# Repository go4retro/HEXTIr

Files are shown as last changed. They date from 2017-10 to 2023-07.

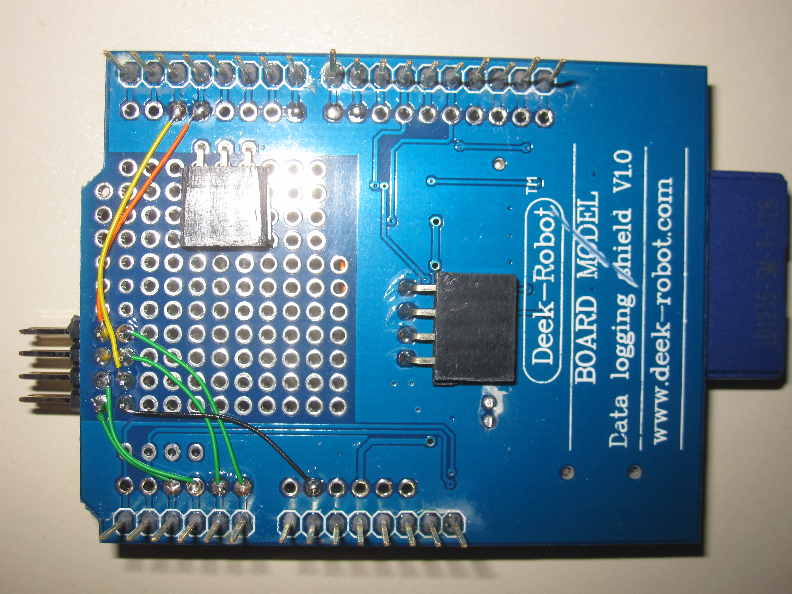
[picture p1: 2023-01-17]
doc/arduino/Arduino SD Shield Bottom.jpg

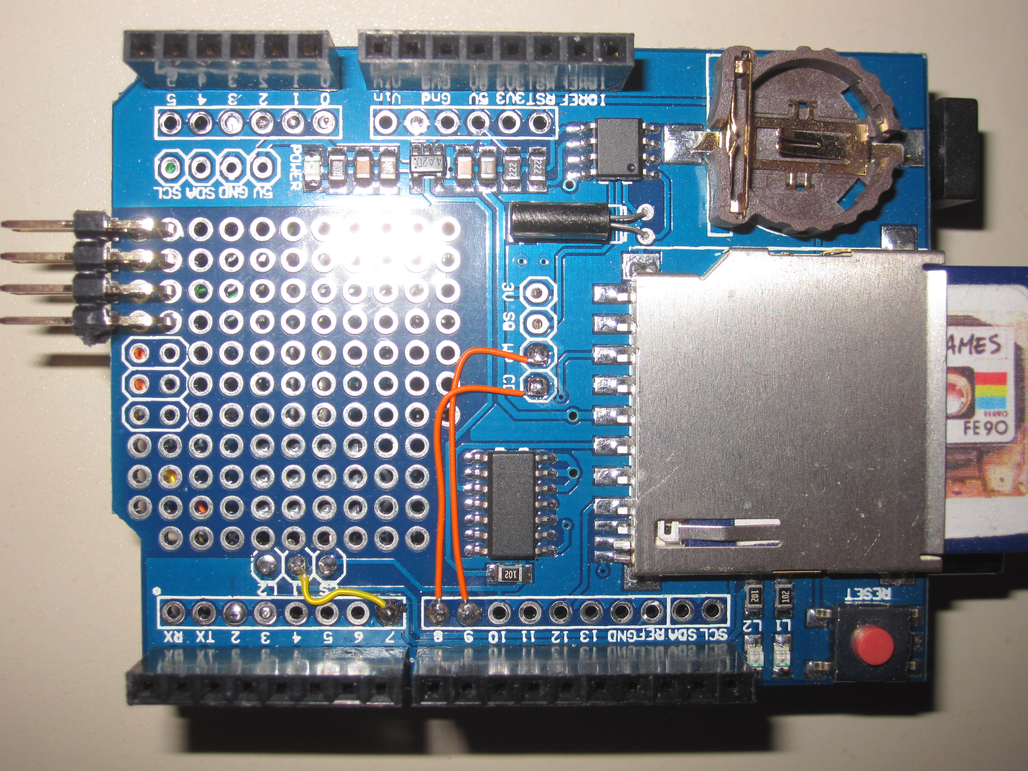
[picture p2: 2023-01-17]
doc/arduino/Arduino SD Shield Top.jpg

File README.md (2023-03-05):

# HEXTIr
TI HEX-BUS SD Drive Interface
Copyright (C) 2017-20  Jim Brain

## Description
Coupled with an Atmel ATMEGA328 microcontroller (either as a standalone PCB or an 
Arduino UNO, Nano, etc. development board), this firmware implements the functionality
of the various HEXBUS peripherals:

* Secure Digital (SD) based random access disk drive at device # 100
* RS232 port at device # 20
* RS232-based printer port at device #10
* RTC-based clock at device 230

## Implementation
### Arduino Implementation
Configure the Arduino IDE for the specific board in use. Adjust pin mappings in config.h
if the board does not use Arduino UNO mappings.  Once configured, load the 
src.ino file in the src directory, compile and download the object code to the Arduino
system.

Because the GCC C++ compiler and Arduino IDE settings compile the code slightly differently,
the resulting code size is larger and thus not all features can be enabled.  By default, 
only the driver function is enabled in the Arduino build.  You can optionally enable some
of the other peripherals by uncommenting lines in config.h:

```
#elif CONFIG_HARDWARE_VARIANT == 4
/* ---------- Hardware configuration: Old HEXTIr Arduino ---------- */

#define INCLUDE_DRIVE
//#define INCLUDE_CLOCK
//#define INCLUDE_SERIAL
//#define INCLUDE_PRINTER
```

The code has been successfully compiled using Arduino IDE 1.8.19 and 2.0.3.

### Native Implementation
The best code size is obtained by compiling the code natively via the AVR-GCC toolchain.

**To use the PCB design in the PCB directory, run the following make command:**

> make CONFIG=config clean all fuses program

**To use an Arduino UNO with a SD Card shield, run the following make command:**

> make CONFIG=config-arduino clean all fuses program

You may need to adjust the avrdude settings in the respecive config files in the 
main directory.

Native and Arduino builds differ only in the pin mappings.  All features are enabled
in both builds.  If space becomes an issue, you can comment out specific peripherals in config.h:

```
#define INCLUDE_DRIVE
#define INCLUDE_CLOCK
#define INCLUDE_SERIAL
#define INCLUDE_PRINTER
```

## PCB Design Copyright

This project's PCB files are free designs; you can redistribute them 
and/or modify them under the terms of the Creative Commons
Attribution-ShareAlike 4.0 International License.

You should have received a copy of the license along with this
work. If not, see <http://creativecommons.org/licenses/by-sa/4.0/>.

These files are distributed in the hope that they will be useful,
but WITHOUT ANY WARRANTY; without even the implied warranty of
MERCHANTABILITY or FITNESS FOR A PARTICULAR PURPOSE.  See the
license for more details.

## Firmware Copyright

This program is free software; you can redistribute it and/or modify
it under the terms of the GNU General Public License as published by
the Free Software Foundation; version 2 of the License only.

This program is distributed in the hope that it will be useful,
but WITHOUT ANY WARRANTY; without even the implied warranty of
MERCHANTABILITY or FITNESS FOR A PARTICULAR PURPOSE.  See the
GNU General Public License for more details.

You should have received a copy of the GNU General Public License
along with this program; if not, write to the Free Software
Foundation, Inc., 59 Temple Place, Suite 330, Boston, MA  02111-1307  USA

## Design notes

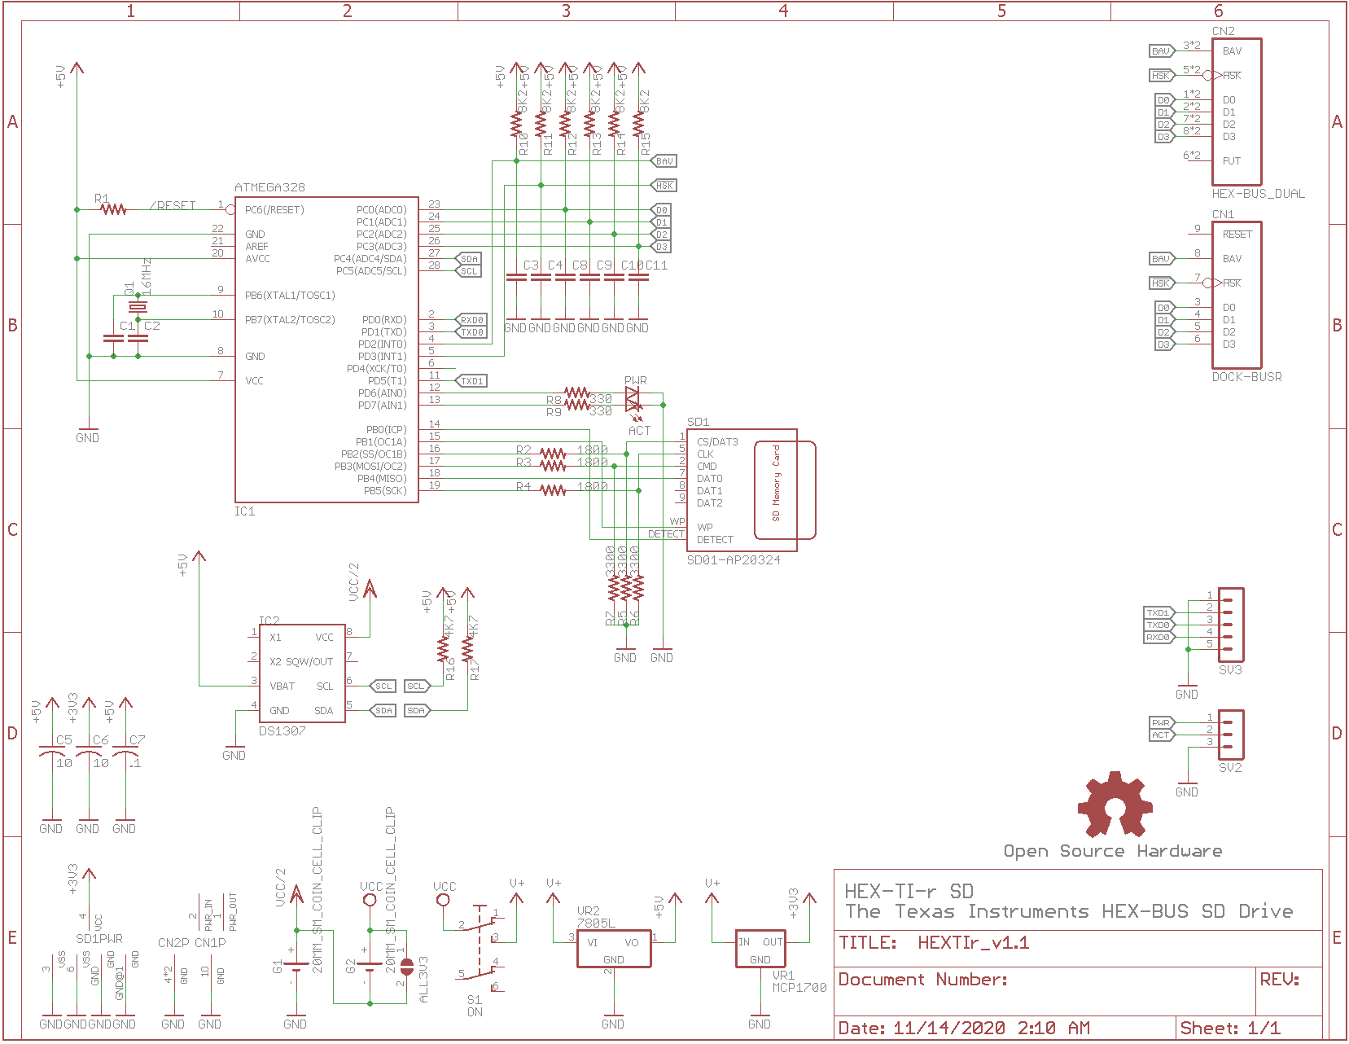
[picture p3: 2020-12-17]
pcb/HEXTIr_v1.1 Schematic.png

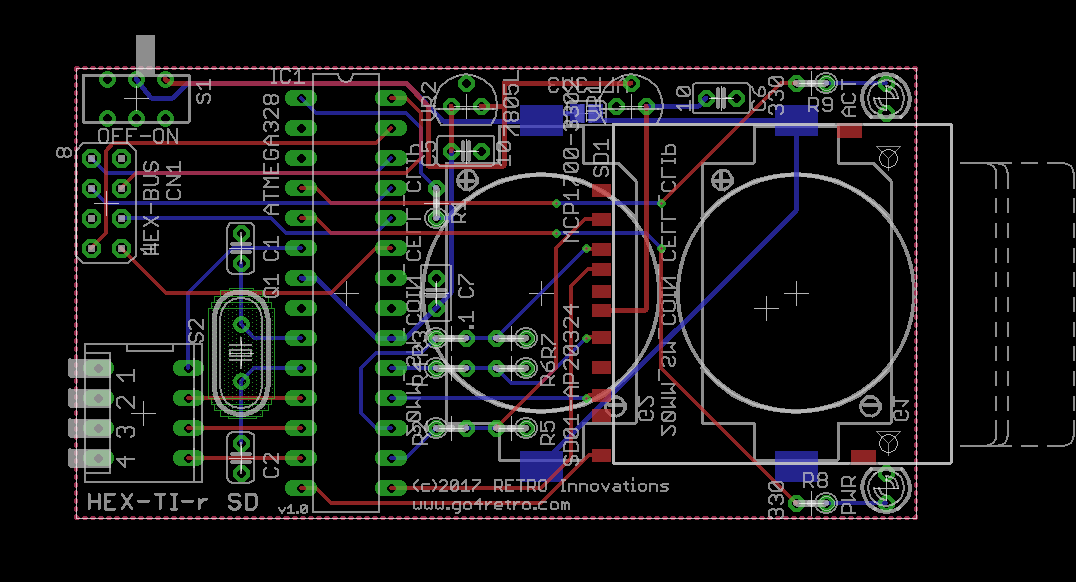
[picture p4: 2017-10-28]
pcb/HEXTIr PCB.png

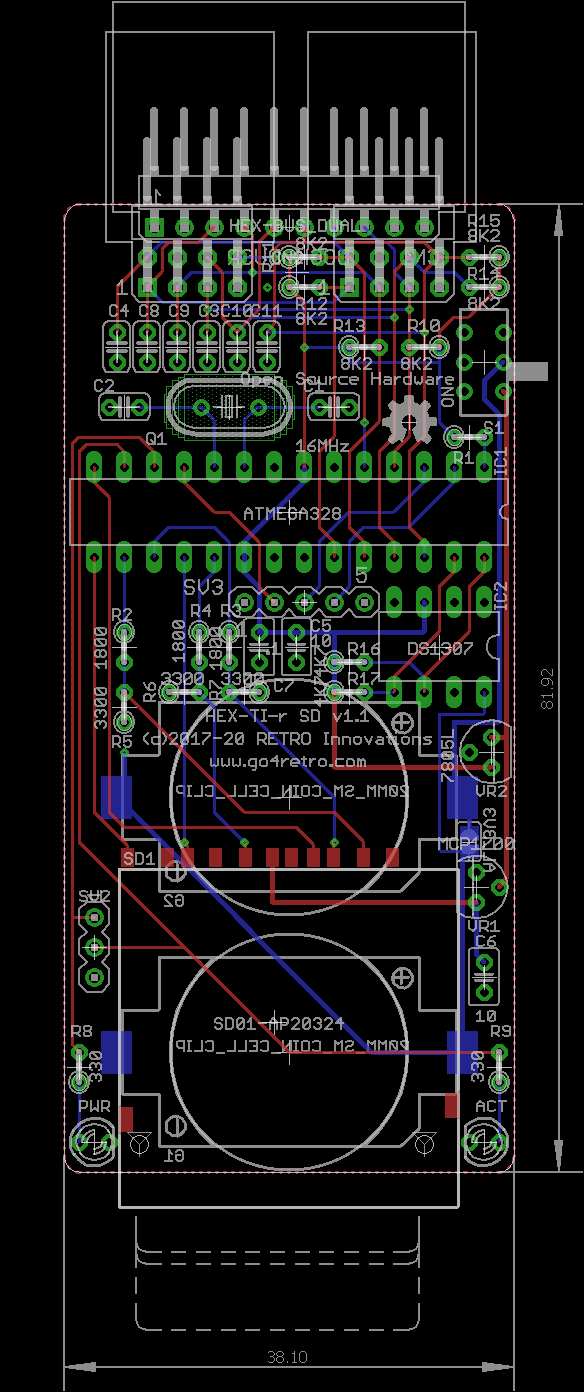
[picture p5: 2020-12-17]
pcb/HEXTIr_v1.1 PCB.png

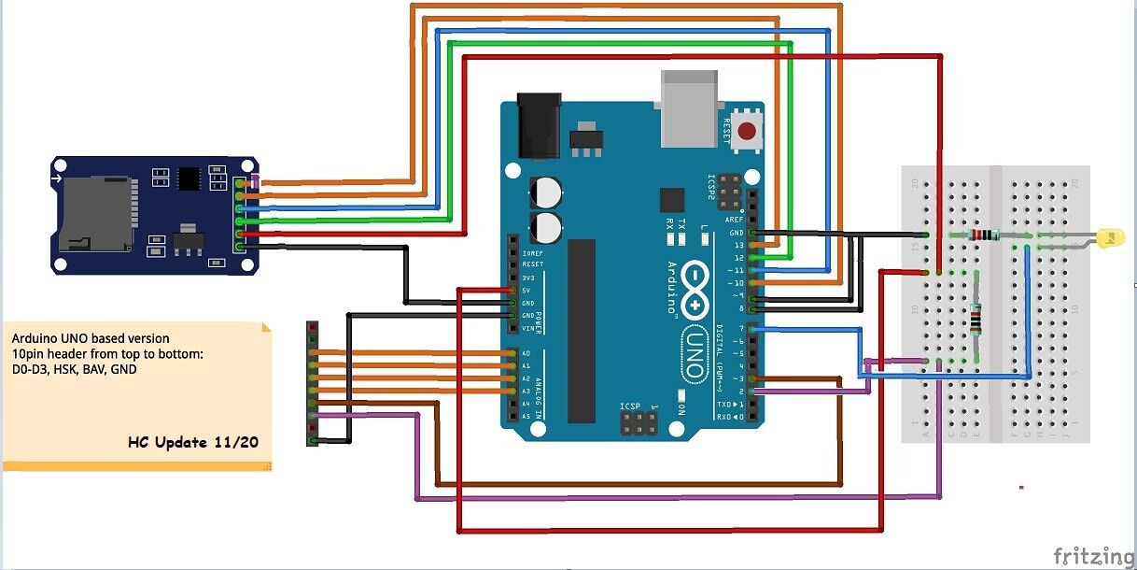
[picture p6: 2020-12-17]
pcb/Fritzing/HexBusSDUno_bb.JPG

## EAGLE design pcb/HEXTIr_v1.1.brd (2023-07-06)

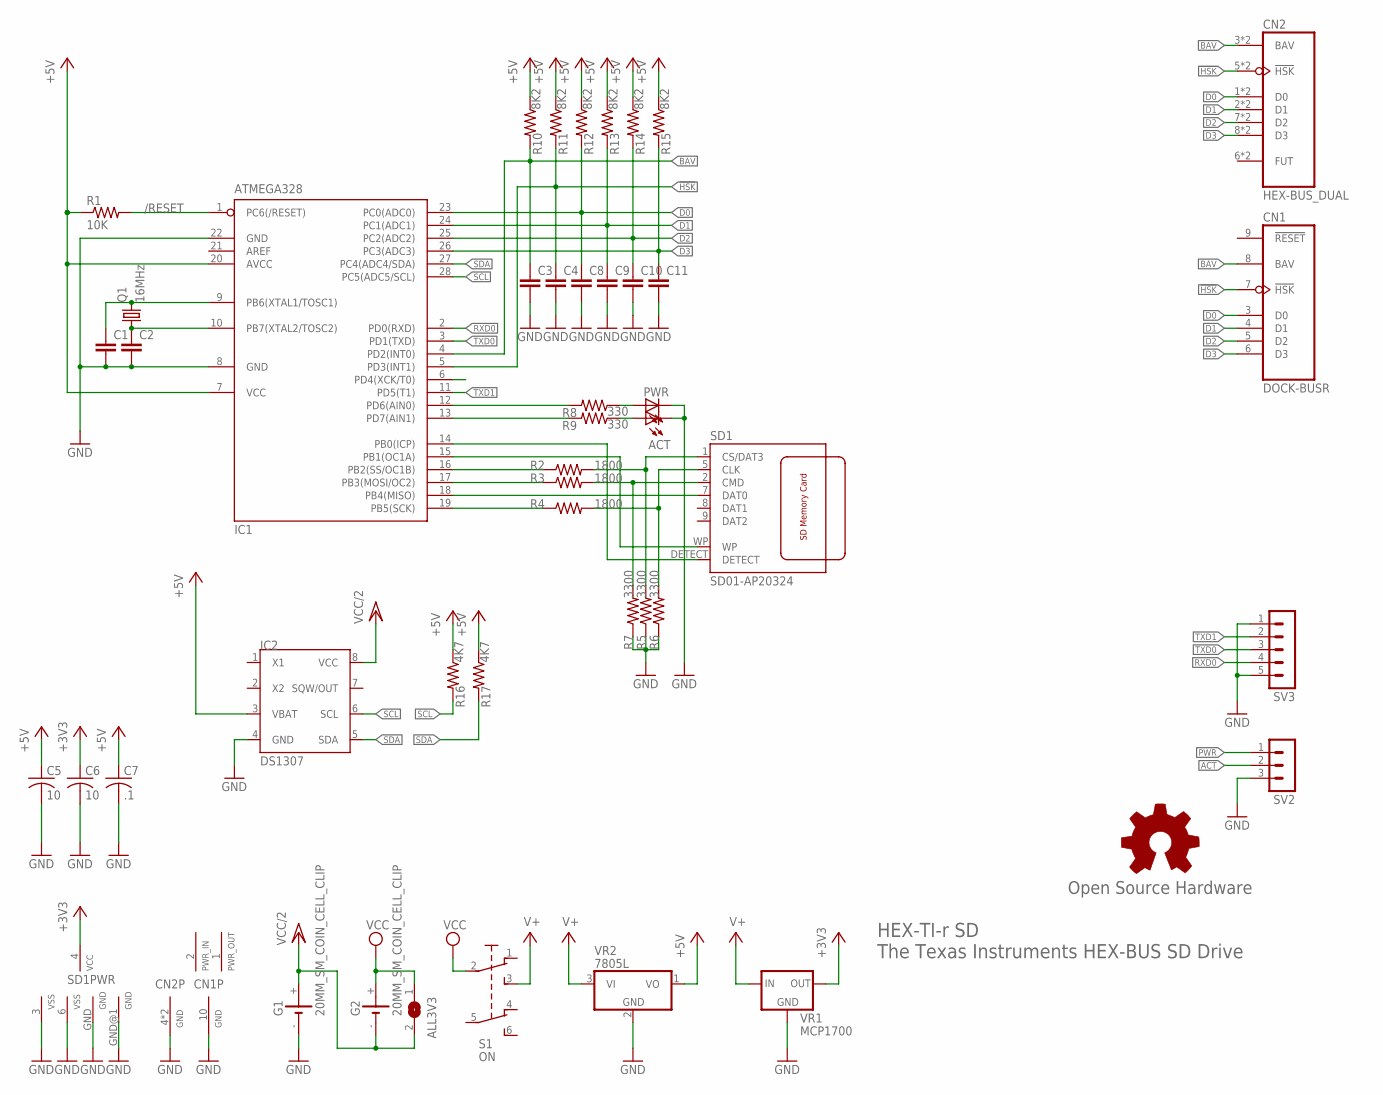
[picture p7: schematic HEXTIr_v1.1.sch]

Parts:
ACT: LED3MM
ALL3V3: SJ
C1, C2, C3, C4, C8, C9, C10, C11: C-EU025-024X044; C025-024X044
C5, C6: 10; C025-025X050
C7: .1; C025-025X050
CN1: DOCK-BUSR; DOCK-BUS-RP
CN2: HEX-BUS_DUAL
G1, G2: 20MM_SM_COIN_CELL_CLIP
GOLD_ORB_SM1: Open Source Hardware; OSHW_5MM
IC1: ATMEGA328; DIL28-3
IC2: DS1307; DIL08
PWR: LED3MM
Q1: 16MHz; HC49U-V
R1: 10K; 0204V
R2, R3, R4: 1800; 0204V
R5, R6, R7: 3300; 0204V
R8, R9: 330; 0204V
R10, R11, R12, R13, R14, R15: 8K2; 0204V
R16, R17: 4K7; 0204V
S1: ON; TINY-SLIDE
SD1: SD01-AP20324
SV2: MA03-1
SV3: MA05-1
VR1: MCP1700; TO92
VR2: 7805L; TO92

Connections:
!HSK: C4.1, CN1.7 (!HSK), CN2.5 (!HSK), CN2.5' (!HSK), IC1.5 (PD3(INT1)), R11.2
+3V3: C6.1, SD1.4 (3V3), VR1.3 (OUT)
+5V: C5.1, C7.1, IC1.7 (VCC), IC1.20 (AVCC), IC2.3 (VBAT), R1.1, R10.1, R11.1, R12.1, R13.1, R14.1, R15.1, R16.1, R17.1, VR2.1 (VO)
/RESET: IC1.1 (PC6(/RESET)), R1.2
ACT: IC1.13 (PD7(AIN1)), R9.2, SV2.2
B2: C1.1, IC1.9 (PB6(XTAL1/TOSC1)), Q1.2
B3: C2.1, IC1.10 (PB7(XTAL2/TOSC2)), Q1.1
BAV: C3.1, CN1.8 (BAV), CN2.3 (BAV), CN2.3' (BAV), IC1.4 (PD2(INT0)), R10.2
D0: C8.1, CN1.3 (D0), CN2.1 (D0), CN2.1' (D0), IC1.23 (PC0(ADC0)), R12.2
D1: C9.1, CN1.4 (D1), CN2.2 (D1), CN2.2' (D1), IC1.24 (PC1(ADC1)), R13.2
D2: C10.1, CN1.5 (D2), CN2.7 (D2), CN2.7' (D2), IC1.25 (PC2(ADC2)), R14.2
D3: C11.1, CN1.6 (D3), CN2.8 (D3), CN2.8' (D3), IC1.26 (PC3(ADC3)), R15.2
GND: ACT.K (C), C1.2, C2.2, C3.2, C4.2, C5.2, C6.2, C7.2, C8.2, C9.2, C10.2, C11.2, CN1.10 (GND), CN2.4 (GND), CN2.4' (GND), G1.-, IC1.8 (GND), IC1.22 (GND), IC2.4 (GND), PWR.K (C), R5.1, R6.1, R7.1, SD1.3 (VSS), SD1.6 (VSS), SD1.GND, SD1.GND@1 (GND), SV2.3, SV3.1, SV3.5, VR1.1 (GND), VR2.2 (GND)
MISO: IC1.18 (PB4(MISO)), SD1.7 (DAT0)
MOSI: IC1.17 (PB3(MOSI/OC2)), R3.1
unnamed: R2.2, R5.2, SD1.1 (CS/DAT3)
unnamed: R3.2, R7.2, SD1.2 (CMD)
unnamed: R4.2, R6.2, SD1.5 (CLK)
unnamed: IC1.15 (PB1(OC1A)), SD1.WP
unnamed: IC1.14 (PB0(ICP)), SD1.DETECT
unnamed: ACT.A, R9.1
unnamed: PWR.A, R8.1
PWN_IN: CN1.2 (PWN_IN)
PWR: IC1.12 (PD6(AIN0)), R8.2, SV2.1
PWR_OUT: CN1.1 (PWR_OUT)
RXD0: IC1.2 (PD0(RXD)), SV3.4
SCK: IC1.19 (PB5(SCK)), R4.1
SCL: IC1.28 (PC5(ADC5/SCL)), IC2.6 (SCL), R16.2
SDA: IC1.27 (PC4(ADC4/SDA)), IC2.5 (SDA), R17.2
SS: IC1.16 (PB2(SS/OC1B)), R2.1
TXD0: IC1.3 (PD1(TXD)), SV3.3
TXD1: IC1.11 (PD5(T1)), SV3.2
V+: S1.3 (S), VR1.2 (IN), VR2.3 (VI)
VCC: ALL3V3.1, G2.+, S1.2
VCC/2: ALL3V3.2, G1.+, G2.-, IC2.8 (VCC)

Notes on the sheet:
HEX-TI-r SD The Texas Instruments HEX-BUS SD Drive

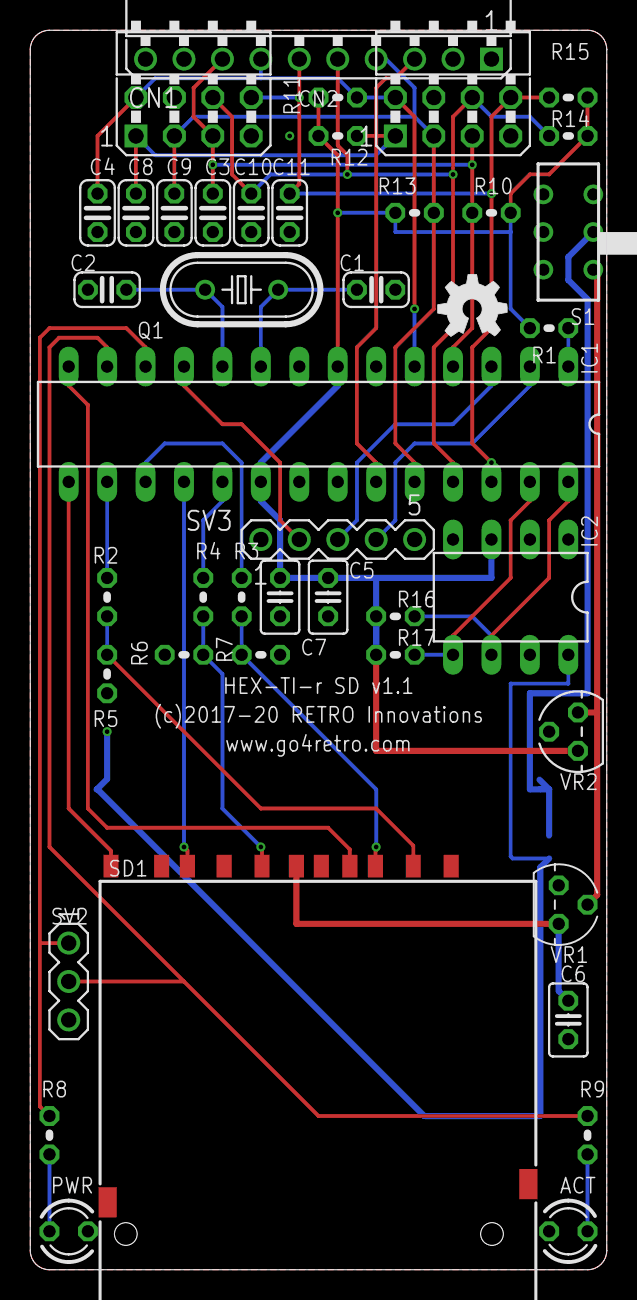
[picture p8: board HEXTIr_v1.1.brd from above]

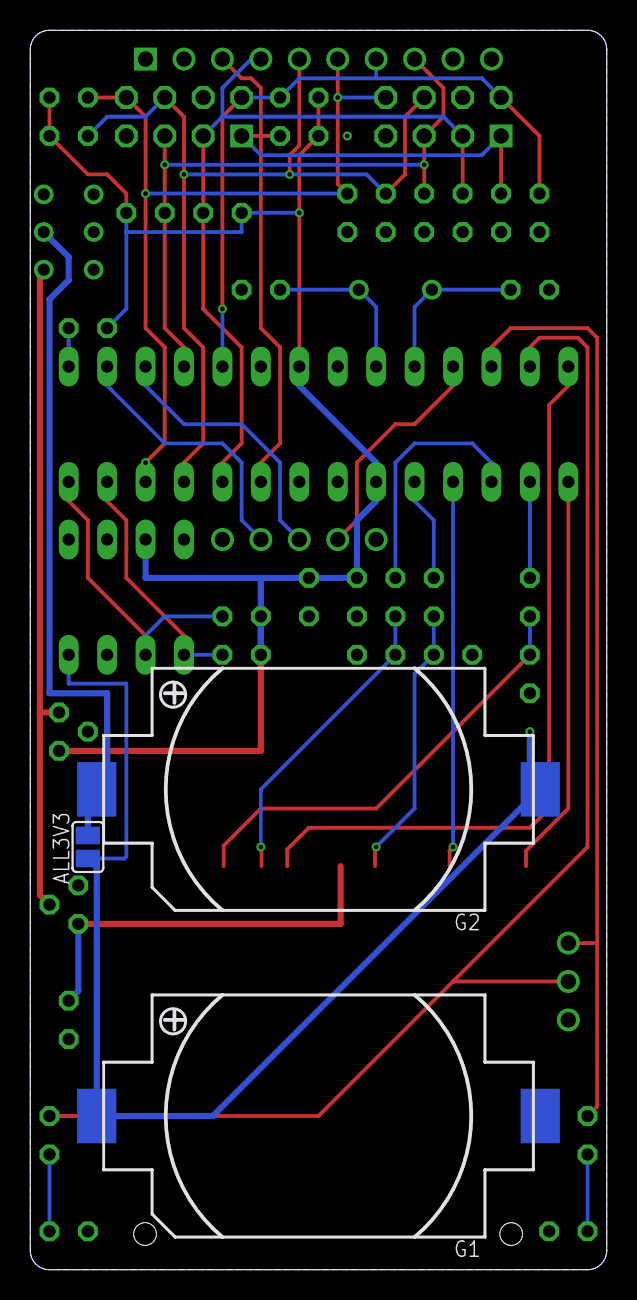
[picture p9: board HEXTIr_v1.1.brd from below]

Board: 2 copper layers, 38.1 x 81.9 mm, 45 parts (3 on the bottom side), 33 nets.

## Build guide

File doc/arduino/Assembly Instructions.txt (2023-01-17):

Arduino pin mapping:

HEX D0->Arduino A0
HEX D1->Arduino A1
HEX D2->Arduino A2
HEX D3->Arduino A3
HEX HSK->Arduino 3
HEX BAV->Arduino 2
Solder CD pin to 8
Solder WP pin to 9
Solder Arduino pin A5 to LED L1
HEX GND to GND

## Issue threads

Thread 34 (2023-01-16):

It would be nice if the README.md detailed the distinctions between the 2 hex files in the repository.

jedimatt42, 2023-01-16:
Arduino build chains get out of date, and it is nice that there appears to be binaries in here to program directly. But they appear to be for different boards, with no explicit documentation of purpose.

Are they built with all the options? as there is info about enabling and disabling different features to fit in different chips.

Which wiring diagrams do they match to?

Please update the documentation.

go4retro, 2023-01-17:
v1 PCB build config and binaries were missing non drive peripherals.  Refreshed builds and updated README.  Let me know if the new README is sufficient, or make a pull request if desired.

Closed 2023-01-17.

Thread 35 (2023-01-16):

This wiring doesn't work with the current or rev v0.9.3.3 328p-arduino hex files

jedimatt42, 2023-01-16:
https://github.com/go4retro/HEXTIr/blob/00074e3dfe0678920cc521dee59f99fec876bfa7/doc/arduino/Assembly%20Instructions.txt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

Arduino L1 needs to go to Arduino pin 7
and then double check HEX-BAV and HEX-HSK, one goes to arduino pin 2.

These pictures floated in a circle and work with the committed hex file:

- https://postlmg.cc/V0JNJZc4
- https://postimg.cc/kVCDTyxX

go4retro, 2023-01-17:
Thanks for noting.  Those instructions were created early in development, and we moved the HSK pin to take advantage of a sleep capability.

Closed 2023-01-17.

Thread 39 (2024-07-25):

switching to a receive buffer for UART breaks other things

classilla, 2024-07-25:
While working with the serial emulation, I noticed that `LINPUT#` will only ever return a single character, and doesn't buffer them. Characters are missing regardless of baud rate. The real RS-232 Hexbus device returns entire lines of data at any supported speed.

I suspected the problem was in `serial.cpp` where it only reports a single character if `uart0_data_available()` is true. The correct way to solve this is of course to have a proper receive buffer as well as a transmit buffer. However, when I turned this on and added fixes for proper constants in the m328p, the device is now unresponsive to _any_ hexbus device number (error 255). Reflashing without this change restores previous behaviour.

What have I forgotten? Diff attached.
[serial.attempt.2.diff.txt](https://github.com/user-attachments/files/16370767/serial.attempt.2.diff.txt)

go4retro, 2024-07-26:
I'll see if I can replicate and create a small test case for the UART functions.

classilla, 2024-07-26:
I should note that the current serial emulation works fine in Memo Processor as a simple dummy terminal. This issue pops up when trying to do RS-232 transfers of greater than one byte, which is why I think the fault is there. I'm pretty sure I have the correct ISR for the receive side, I'm just baffled as to why that would affect its ability to make Hexbus transfers generally.

go4retro, 2024-08-27:
> I'll see if I can replicate and create a small test case for the UART functions.

I finally got some time to strip all out of the project and make a test.

https://github.com/go4retro/TestSerial

I applied your mods (thanks for them), and this test has issues, but I think it's because of the code in data_available.  I ran the test using an arduino and pushed a text file to the unit and watched how data_available behaved.

Can you try and see if you get good behavior?

Jim

classilla, 2024-09-05:
I can't seem to compile that on my Arduino Uno board:

```
diff --git a/config b/config
index 08bd181..18f02b4 100644
--- a/config
+++ b/config
@@ -45,19 +45,23 @@ CONFIG_UART_DEBUG_FLUSH=y

 # Initial Baud rate of the UART
 CONFIG_UART_BAUDRATE=300
 CONFIG_UART_BUF_SHIFT=8

 # Select which hardware to compile for
 # Valid values:
 #   1 - v1 board
-CONFIG_HARDWARE_VARIANT=1
-CONFIG_AVRDUDE_PROGRAMMER=arduino
-CONFIG_AVRDUDE_PORT=COM3
+#CONFIG_HARDWARE_VARIANT=1
+#CONFIG_AVRDUDE_PROGRAMMER=arduino
+#CONFIG_AVRDUDE_PORT=COM3
+
+CONFIG_HARDWARE_VARIANT=2
+CONFIG_AVRDUDE_PROGRAMMER=usbtiny
+CONFIG_AVRDUDE_PORT=usb
```

Is all the stuff supposed to be gone from `src/config.h` in that repo?

go4retro, 2024-09-05:
Apologies, I'll add in the stuff you need and make sure it compiles.  How do you compile the code?  Do you use the Arduino IDE, or the Makefile?

classilla, 2024-09-05:
The `Makefile` (I compile from the command line).

go4retro, 2024-09-06:
Ok, open an issue there with your command line and the error output.  I'll work to replicate.  Should be an easy fix, as there's not much code left.

classilla, 2024-09-10:
OK: https://github.com/go4retro/TestSerial/issues/1

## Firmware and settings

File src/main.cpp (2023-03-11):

/*
    HEXTIr-SD - Texas Instruments HEX-BUS SD Mass Storage Device
    Copyright Jim Brain and RETRO Innovations, 2017

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
    main.c: Main application
*/

#include <stddef.h>
#include <string.h>
#include <avr/pgmspace.h>
#include <util/delay.h>

#include "config.h"
#include "clock.h"
#include "debug.h"
#include "drive.h"
#include "eeprom.h"
#include "hexbus.h"
#include "hexops.h"
#include "led.h"
#include "printer.h"
#include "powermgmt.h"
#include "registry.h"
#include "rtc.h"
#include "serial.h"
#include "swuart.h"
#include "timer.h"
#include "uart.h"

// Our registry of installed devices, built during initialization.
registry_t  registry;

/*
   hex_reset_bus() -
   This command is normally used with device code zero, and must actually
   do something if files are open (or printer is open).
   Close any open files to ensure they are sync'd properly.  Close the printer if
   open, and ensure our file lun tables are reset.
   There is NO response to this command.
*/
static void hex_reset_bus(pab_t *pab __attribute__((unused))) {

  debug_puts_P("Reset Bus\r\n");

  // We ONLY do all devices if the command is directed to device 0.
  drv_reset();
  prn_reset();
  ser_reset();
  clk_reset();
  // release the bus ignoring any further action on bus. no response sent.
  hex_finish();
  // wait here while bav is low
  while ( !hex_is_bav() ) {
    ;
  }
}


static void execute_command(pab_t *pab) {
  cmd_proc  handler;
  cmd_op_t  *op;
  uint8_t   i = 0;
  uint8_t   j;
  uint8_t   cmd;

  while ( i < registry.num_devices ) {
    // does the incoming PAB have a device in this group in the registry?
    if ( registry.entry[ i ].dev_cur == pab->dev ) {
      // If so...
      // this entry will handle our device code.
      // Search for a matching command index now.
      op = registry.entry[ i ].oplist;
      j = 0;
      // Find a matching command code in this device's table, if present
      do {
        cmd = pgm_read_byte( &op[j].command );
        j++;
      } while ( ( cmd != HEXCMD_INVALID_MARKER ) && cmd != pab->cmd );
      // If we found the command, we have the index to the operations routine
      if ( cmd == pab->cmd ) {
        // found it!
        j--;  // here's the cmd index
        // fetch the handler for this command for this device group.
        handler = (cmd_proc)pgm_read_word( &op[j].operation );
        (handler)( pab );
        // and exit the command processor
        return;
      }
      // If we have a supported device but not a supported command...
      hex_unsupported(pab);
      // we report and unsupported command and return
      return;
    }
    // otherwise; let's move to possibly the next device group in the registry
    i++;
  }
  // If the device is not supported at all, then treat as a null.
  // Release the HSK line and simply wait for BAV to go high indicating end of message.
  // This is the best we can do, as someone else may be acting on this message.
  hex_null(pab);
}


//
// Default registry for global bus support (device 0).
//
static const cmd_op_t ops[] PROGMEM = {
                                       {HEXCMD_RESET_BUS, hex_reset_bus},
                                       {HEXCMD_NULL, hex_null},
                                       {HEXCMD_INVALID_MARKER, NULL}
                                      };


static inline void bus_init(void) {
  reg_add(DEV_ALL, DEV_ALL, DEV_ALL, ops);
}


/*
   setup() - In Arduino, this will be run once automatically.
   Building non-Arduino, we'll call it once at the beginning
   of the main() function.
*/

void setup(void) {
  board_init();
  pwr_init();
  debug_init();

  sei();

  ee_get_config();

  disk_init();
  hex_init();
  leds_init();
  timer_init();
  bus_init();
  clk_init();
  drv_init();
  ser_init();
  prn_init();

  wakeup_pin_init();
}


int main(void) __attribute__((OS_main));
//int  __attribute__ ((noreturn)) main(void);
int main(void) {

  // Variables used common to both Arduino and makefile builds
  uint8_t i = 0;
  uint8_t ignore_cmd = FALSE;
  pab_raw_t pabdata;
  hexerror_t res;
  rtc_type_t rtc_type;
#ifdef HAVE_HOTPLUG
  uint8_t disk_state_old = 0;
#endif

  setup();

  rtc_type = rtc_get_type();

  pabdata.pab.cmd = 0;
  pabdata.pab.lun = 0;
  pabdata.pab.record = 0;
  pabdata.pab.buflen = 0;
  pabdata.pab.datalen = 0;

  debug_puts_P("\r\n" TOSTRING(CONFIG_HARDWARE_NAME) " Version: " VERSION);
  debug_putcrlf();

  while (TRUE) {

    set_busy_led( FALSE );

    while (hex_is_bav()) {
      // sleep until BAV falls. If low, HSK will be low.(if power management enabled, if not this is nop)
      if(rtc_type != RTC_TYPE_SW) {  // can't sleep if RTC is SW
        if(ser_is_open() || prn_is_open()) { // snooze
          if(!uart_data_tosend() && !swuart_data_tosend()) {
            pwr_sleep(SLEEP_IDLE);
          }
        } else {
          pwr_sleep(SLEEP_STANDBY);
        }
      }
    }

#ifdef INCLUDE_POWERMGMT
    // BAV low woke us up. Wait to see if we
    // get a HSK low, if so, drop our HSK and then proceed.
    // We do this here, because HSK must be held low after transmitter pulls it low
    // within a very short window of time (< 8us).
    hex_capture_hsk();
#endif

    debug_putc('^');
    set_busy_led( TRUE ); // TODO why do we set busy led here?

    while (!hex_is_bav()) {

      while ( i < 9 ) {
        pabdata.raw[ i ] = i;
        res = hex_recv_byte( &pabdata.raw[ i ] );
#ifdef HAVE_HOTPLUG
        // Since we defer mounting the drive until a file is requested,
        // this state may exist for some time.
        if(disk_state_old != disk_state)
          /* This seems to be a nice point to handle card changes */
          switch(disk_state) {
          case DISK_CHANGED:
          case DISK_REMOVED:
            /* If the disk was changed the buffer contents are useless */
            // we need to clean out all disk buffers
            //free_multiple_buffers(FMB_ALL);
            //change_init();
            //fatops_init(0);
            drv_init();
            debug_putc('D');
            break;
          case DISK_ERROR:
          default:
            break;
          }
        disk_state_old = disk_state;
#endif


        if ( res == HEXERR_SUCCESS ) {
          i++;
        } else {
          ignore_cmd = TRUE;
          i = 9;
          hex_release_bus();
        }
      }

      if ( !ignore_cmd ) {
        ignore_cmd = TRUE;
        for (uint8_t j = 0; j < registry.num_devices; j++) {
          if(registry.entry[j].dev_cur == pabdata.pab.dev) {
            // we should cache the index...
            ignore_cmd = FALSE;
            break;
          }
        }
      }
      if ( !ignore_cmd ) {
        if (i == 9) {
          // exec command
          debug_putcrlf();
          if ( pabdata.pab.dev == 0 && pabdata.pab.cmd != HEXCMD_RESET_BUS ) {
            pabdata.pab.cmd = HEXCMD_NULL; // change out to NULL operation and let bus float.
          }
          execute_command( &(pabdata.pab) );
          ignore_cmd = TRUE;  // in case someone sends more data, ignore it.
        }
      } else {
        debug_putc('%');
        debug_puthex(pabdata.raw[0]);
        i = 0;
        hex_release_bus();
        while (!hex_is_bav() )  // wait for BAV back high, ignore any traffic
          ;
        ignore_cmd = FALSE;
      }
    }

    debug_putcrlf();
    i = 0;
    ignore_cmd = FALSE;
  }
}

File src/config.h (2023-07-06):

/*
    HEXTIr-SD - Texas Instruments HEX-BUS SD Mass Storage Device
    Copyright Jim Brain and RETRO Innovations, 2017

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
    config.h: User-configurable options to simplify hardware changes and/or
              reduce the code/ram requirements of the code.
*/

#ifndef CONFIG_H
#define CONFIG_H

#include "version.h"

#define STRINGIFY(x) #x
#define TOSTRING(x) STRINGIFY(x)

#ifdef VER_PATCH
#ifdef VER_FIX
  #define VER_TEXT           TOSTRING(VER_MAJOR) "." TOSTRING(VER_MINOR) "." TOSTRING(VER_PATCH) "." TOSTRING(VER_FIX)
#else
  #define VER_TEXT           TOSTRING(VER_MAJOR) "." TOSTRING(VER_MINOR) "." TOSTRING(VER_PATCH)
#endif
#else
  #define VER_TEXT           TOSTRING(VER_MAJOR) "." TOSTRING(VER_MINOR)
#endif
#ifdef VER_PRERELEASE
  #define VERSION "" VER_TEXT TOSTRING(VER_PRERELEASE) ""
#else
  #define VERSION "" VER_TEXT ""
#endif

#define FLASH_MEM_DATA  1

#include <avr/io.h>

#ifdef ARDUINO
#  if defined ARDUINO_AVR_UNO || defined ARDUINO_AVR_PRO || defined ARDUINO_AVR_NANO
#    define CONFIG_HARDWARE_VARIANT   3 // Hardware variant 3 is Arduino, with BAV on D2 for wakeup from standby mode.
      // Variant 3 has been tested on Pro Mini, Uno, and Nano as functional.  Select target platform in the IDE.
#  else
#    error "ARDUINO VARIANT is unknown."
#  endif
#else
 #include "autoconf.h"
#endif

/* ----- Common definitions for all AVR hardware variants ------ */

#define MAX_OPEN_FILES    8
#define BUFSIZE           255
#define UART_DOUBLE_SPEED

#if CONFIG_HARDWARE_VARIANT == 1
/* ---------- Hardware configuration: HEXTIr v1 ---------- */

#  define INCLUDE_DRIVE
#  define INCLUDE_CLOCK
#  define INCLUDE_SERIAL
#  define INCLUDE_PRINTER

#  define HEX_HSK_DDR         DDRD
#  define HEX_HSK_OUT         PORTD
#  define HEX_HSK_IN          PIND
#  define HEX_HSK_PIN         _BV(PIN3)

#  define HEX_BAV_DDR         DDRD
#  define HEX_BAV_OUT         PORTD
#  define HEX_BAV_IN          PIND
#  define HEX_BAV_PIN         _BV(PIN2)

#  define HEX_DATA_DDR        DDRC
#  define HEX_DATA_OUT        PORTC
#  define HEX_DATA_IN         PINC
#  define HEX_DATA_PIN        (_BV(PIN0) | _BV(PIN1) | _BV(PIN2) | _BV(PIN3))

#  define LED_BUSY_DDR        DDRD
#  define LED_BUSY_OUT        PORTD
#  define LED_BUSY_PIN        _BV(PIN7)

#  define HAVE_SD
#  define SD_CHANGE_HANDLER     ISR(PCINT0_vect)
#  define SD_SUPPLY_VOLTAGE     (1L<<21)

/* 250kHz slow, 2MHz fast */
#  define SPI_DIVISOR_SLOW 64
#  define SPI_DIVISOR_FAST 8


static inline void sdcard_interface_init(void) {
  DDRB  &= ~_BV(PB1);  // wp
  PORTB |=  _BV(PB1);
  DDRB  &= ~_BV(PB0);  // detect
  PORTB |=  _BV(PB0);
  PCICR |= _BV(PCIE0);
  //EICRB |=  _BV(ISC60);
  PCMSK0 |= _BV(PCINT1);
  //EIMSK |=  _BV(INT6);
}


static inline uint8_t sdcard_detect(void) {
  return !(PINB & _BV(PIN0));
}


static inline uint8_t sdcard_wp(void) {
  return PINB & _BV(PIN1);
}


static inline void board_init(void) {
  // turn on power LED
  DDRD  |= _BV(PIN6);
  PORTD |= _BV(PIN6);
}


static inline void wakeup_pin_init(void) {
  DDRD &= ~_BV(PIN2);
}


#  define INCLUDE_POWERMGMT  // Power Management may not be fully available on all platforms
#  define POWER_MGMT_HANDLER  ISR(INT0_vect)

static inline void pwr_irq_enable(void) {
  EICRA |= _BV(ISC01);  // trigger power enable on falling IRQ.
  EIMSK |= _BV(INT0);   // turn on IRQ
}


static inline void pwr_irq_disable(void) {
  EIMSK &= ~_BV(INT0);   // turn off IRQ
}


#elif CONFIG_HARDWARE_VARIANT == 2
/* ---------- Hardware configuration: HEXTIr Arduino ---------- */

#  define INCLUDE_DRIVE
#  define INCLUDE_CLOCK
#  define INCLUDE_SERIAL
#  define INCLUDE_PRINTER

#  define HEX_HSK_DDR         DDRD
#  define HEX_HSK_OUT         PORTD
#  define HEX_HSK_IN          PIND
#  define HEX_HSK_PIN         _BV(PIN3)

#  define HEX_BAV_DDR         DDRD
#  define HEX_BAV_OUT         PORTD
#  define HEX_BAV_IN          PIND
#  define HEX_BAV_PIN         _BV(PIN2)

#  define HEX_DATA_DDR        DDRC
#  define HEX_DATA_OUT        PORTC
#  define HEX_DATA_IN         PINC
#  define HEX_DATA_PIN        (_BV(PIN0) | _BV(PIN1) | _BV(PIN2) | _BV(PIN3))

#  define LED_BUSY_DDR        DDRD
#  define LED_BUSY_OUT        PORTD
#  define LED_BUSY_PIN        _BV(PIN7)

#  define HAVE_SD
#  define SD_CHANGE_HANDLER     ISR(PCINT0_vect)
#  define SD_SUPPLY_VOLTAGE     (1L<<21)

/* 250kHz slow, 2MHz fast */
#  define SPI_DIVISOR_SLOW 64
#  define SPI_DIVISOR_FAST 8


static inline void sdcard_interface_init(void) {
  DDRB  &= ~_BV(PB0);  // detect
  PORTB |=  _BV(PB0);
  DDRB  &= ~_BV(PB1);  // wp
  PORTB |=  _BV(PB1);
  PCICR |= _BV(PCIE0);
  //EICRB |=  _BV(ISC60);
  PCMSK0 |= _BV(PCINT0);
  //EIMSK |=  _BV(INT6);
}


static inline uint8_t sdcard_detect(void) {
  return !(PINB & _BV(PIN0));
}


static inline uint8_t sdcard_wp(void) {
  return PINB & _BV(PIN1);
}


static inline void board_init(void) {
}


static inline void wakeup_pin_init(void) {
  DDRD &= ~_BV(PIN2);
}
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

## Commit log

2017-10-28 Try to fix glitching HSK line
    [config.h]
2017-10-28 Remove glitch removal code (unneeded) and fix timing issue in hex_write
    [config.h]
2017-10-28 Add research data from Peter Engels
    [datastreams.xlsx]
2017-10-28 Listen only on single device ID
2017-10-28 v1 PCB Design created (EAGLE v7 format)
    [HEXTIr_v1.brd, HEXTIr_v1.sch]
2017-10-29 Initial support for POWER, BUSY, and ERROR LEDs and device number switch config
    [config.h]
2017-10-29 Change device numbering from 100-115 to 100-107 and 108-117, to match device ID set in HexBus spec.
2017-10-29 PCB and schematic updates
    [HEXTIr_v1.brd, HEXTIr_v1.sch]
2017-10-29 Remove uIEC testing config
    [HEXTIr_v1.sch]
2017-10-29 Clean up flowerbox
2017-10-31 More support for ATMEGA328 and fix for fuses make target
2017-10-31 Switch to MEGA328 for development
2017-11-26 PCB tweaks
    [HEXTIr_v1.brd, HEXTIr_v1.sch]
2017-12-17 Fixed device selection code
    [config.h]
2017-12-17 Minor updates to schematic
    [HEXTIr_v1.sch]
2018-07-02 Initial support for Arduino Uno dev board
2018-07-02 Working Arduino codebase
    [HEXTIr_v1.brd, HEXTIr_v1.sch]
2020-04-10 Small bug fixes and document fix
    [config.h]
2020-05-16 A bit of code cleanup and pics of Arduino SD Shield wiring
2020-06-28 M5dk2n catalog (#7)
    * List PGM files in SD card root directory and run selected program.
    * OLD-PGM version of the catalog.
    * OLD-PGM version of the catalog. Some refactoring.
    * OLD-PGM version of the catalog. Fixed long and short file names.
    * OLD-PGM version of the catalog. Refactoring.
    * OPEN/INPUT variant added.
    * Comment added.
    * Added volume label attribute (DIR,VOL,FIL).
    * Delete LOAD.B74 example.
    * Add in code to do a dir read without creating file on disk
    * M5dk2n catalog (#6)
    * OPEN/INPUT variant of catalog added. Work in progress.
    * Bytes to KB function.
    * Function for files to skip. Some refatcoring.
    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
    [config.h]
2020-08-29 Libmerge (#17)
    * Initial Stephen Reid update commit. make does not work, only Arduino build
    * Cleaned up some #ifdefs around ARDUINO, and massaged dir structure and INO filename so both will compile. Removed lost of included C files from sketch, and moved all sketch code to main.cpp. Also added Reid's Fritzing schematic files for the Arduino
    * Additional updates and cleanup, and first run at a function vector table
    * Major refactoring and switch to function vectors for various commands
    * A bit more code re-org, and added some flowerboxes.
    * activity led and power management update
    Ensure that the activity LED is not illuminated while we sleep between messages when power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
    [HexBusSDUno.fzz]
2020-09-01 Add support for 4 year date in RTC update, replace sizeof(buffer) with constant, and fix LED issue (line commented out for debugging)
    [printer.cpp, serial.cpp]
2020-09-04 Bug fix for writing files > BUFSIZE, fix HW version 1 compile and enable bootloader.
    [config.h, main.cpp]
2020-09-19 Added support for chdir and mkdir. Usage: open #1,"100.md subdir":close #1 or open #1,"100.cd subdir":close #1
    Changed catalog.cpp to respect the current working directory.
2020-09-20 Moved cd, md from OPEN to PRINT. New usage: OPEN #1,"100" PRINT #1,"md /jim" CLOSE #1
2020-09-22 Added support for renaming files and directories. Usage: open #1,"100" print #1,"rn newname=oldname" close #1
2020-09-23 Added support for renaming files and directories, multiple commands in a print statement, see doc/handling_directories.txt
2020-10-02 Updated BASIC files, changed rd command to del in drive.cpp and a small fix in catalog.cpp.
    [config.h, debug.cpp]
2020-10-02 Major code refactoring, additional features, and bug fixes (#23)
    * Peter Engels file support additions
    * updated working cc40 test apps, corrected operation on writing past end of file.
    * Remove a few dependencies and fix open flags.
    * added more BASIC examples
    * added support for data files in DISPLAY and INTERNAL mode. INTERNAL files may be RELATIVE. Added a special LUN 255 for reading, writing and verifying RAM/ROM images. Fixed the SYNTAX ERROR issue on RUN "100.$"
    * Merge in SD card detection code (#19)
    * Add in alpha support for disk change detection.
    * Fixe issue of truncating files on APPEND of UPDATE
    * Merge in LUN=255 functionality and fix a small $ issue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
    [HEXTIr_v1.brd, HEXTIr_v1.sch, HexBusSDUno.fzz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]
2020-10-03 Revise PCB to align with arduino layout
    [HEXTIr_v1.1.brd, HEXTIr_v1.1.sch]
2020-10-03 Create Arduino-compatible PCB layout
    [HEXTIr_v1.1.brd, HEXTIr_v1.1.sch]
2020-10-04 Fix in catalog.cpp for splitting in dirpath and pattern
    [printer.cpp, serial.cpp]
2020-10-12 Clean up flowerboxes and added in binaries
2020-10-16 Fixed file handling of DISPLAY,RELATIVE files
    [HEXTIr_v1.1.brd, HEXTIr_v1.1.sch]
2020-10-17 Switched back to DISPLAY mode at LUN 0
2020-10-22 Handle DISPLAY mode on LUN 0 (#29)
    * Added examples for use use of DISPLAY,RELATIVE
    * Switched back to DISPLAY mode at LUN 0
    * Workaround for cumulative CRLF behind saved programs
    * VERIFY needs the same workaround, therefore i moved from drv_read to drv_open
    * DISPLAY,RELATIVE was broken. Fixed.
    * EOF in DISPLAY,RELATIVE was broken too, Fixed again.
    * Fix to avoid added CRLF on saving program files. Removed the code to adjust filesize.
    * Fixed drv_open when a buffer length is requested on LUN 0, corrected the VERIFY algorithm.
2020-11-15 v0.9.3.2. Small fix to enable saved config for printer
    [config.h, printer.cpp]
2020-12-05 fix for reading behind EOF
    [printer.cpp]
2020-12-17 Clean up old unused code fragments and start reducing dependence on str*() functions.
    [HEXTIr_v1.1.brd, HEXTIr_v1.1.sch]
2020-12-20 Fixed time-out error on reading large files, reenabled LUN_RAW 254 for raw data files
    [HEXTIr_v1.1.brd, HEXTIr_v1.1.sch]
2020-12-22 Merged KPengels fixes and atetmpted to reduce binary size via refactoring
    [HEXTIr_v1.brd, HEXTIr_v1.sch, HexBusSDUno.fzz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]
2020-12-23 Small fix in clk_close
    [printer.cpp, serial.cpp]
2020-12-24 Clean up a few warnings and finesse Build name for arduino compile
2020-12-30 cat_max_file_length_txt returns a too small buffersize, therefore you might get an error 12 with long filenames
    [main.cpp]
2023-01-17 Updated Arduino pin mappings, fixed license file, clean up some warnings
    [main.cpp]
2023-01-17 Refresh Arduino PCB build
2023-01-17 Refresh v1 PCB binaries
2023-01-17 Updated README.md and refreshed all binaries. Reenabled all functions for v1 PCB
2023-01-17 Compiled on Arduino IDE 1.8.19 and 2.0.3
2023-03-05 Temp fixes to disable Power Mgmt so RS232 works.
    [config.h]
2023-03-07 Updates to tone down aggressive power management
2023-03-11 #include cleanup to allow Arduino compile
2023-07-06 Modify pin settings for base config to PCB v1.1
    [HEXTIr_v1.1.brd, HEXTIr_v1.1.sch]
2024-06-12 Support Memo Processor's communications mode (#37)
    * Fixes for Memo Processor comm mode: support 300bps with double speed, fix line type command
    * Binaries for #37
    [serial.cpp]

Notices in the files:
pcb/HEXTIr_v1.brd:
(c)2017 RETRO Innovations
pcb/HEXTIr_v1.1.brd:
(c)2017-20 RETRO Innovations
